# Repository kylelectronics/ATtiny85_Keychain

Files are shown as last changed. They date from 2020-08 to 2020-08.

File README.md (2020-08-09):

# Lighted Keychain
[madewith](https://img.shields.io/badge/made%20with-KiCad-blue)

ATtiny85-based illuminated PCB keychain featuring an organization symbol.
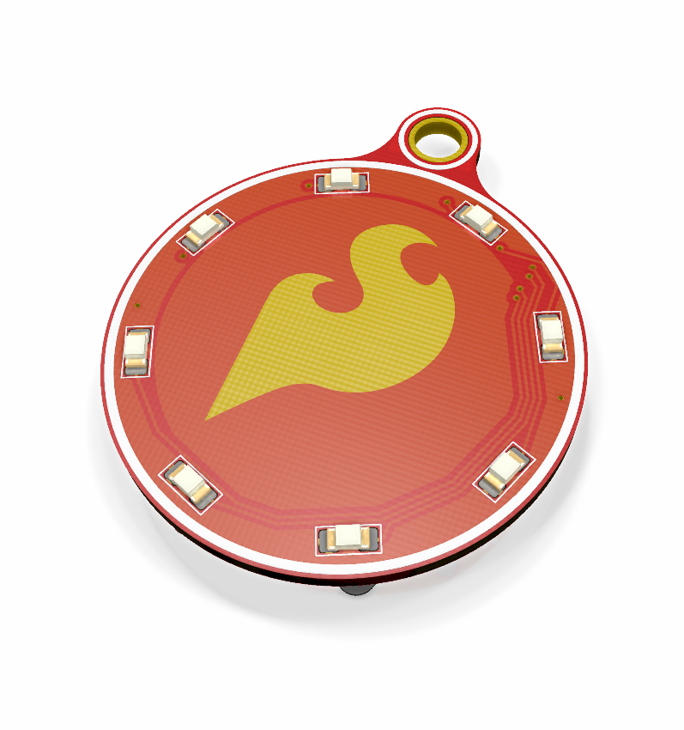
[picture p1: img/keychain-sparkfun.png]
keychain


## Description
Originally developed for Ruddock House of Caltech, this repo contains modified files featuring the flame logo of Sparkfun Electronics.

This is a 1.6" by 1.9" PCB keychain featuring an organization crest on the top copper, based on [https://github.com/ElectronicToast/ruddblink]. A ring of 8 LEDs around the crest is controlled by an ATtiny85 through a 74HC595 shift register. This keychain is intended to be compact and aesthetic, but also simple to hand solder; all packages are SOIC and 0805 or larger.

The keychain is powered by a CR2032 coin cell through the coin cell holder footprint on the back, or through an alternative power source (2.7-5.5V) soldered to those pads.

## Features
- ATtiny85 in SOIC-8 package driving 74HC595 shift register in SOIC-16 package
- PWM-able output
- Power switch
- User pushbutton
- MOSFET polarity protection
- PTC fuse
- No through hole components

## Notes

No input voltage regulation is present. Do not apply more than 5.5 V, the maximum voltage for the ATtiny.

This PCB is designed with KiCad EDA 5.1.6. Schematic and board files may be found under `/attiny85-keychain`, with documentation under `/attiny85-keychain/doc`.

## Author
- Kyle Piper - Undergraduate, Mechanical Engineering, Caltech Class of 2024
- Original design by Ray Sun, Electrical Engineering, Caltech Class of 2020

## License
<br />Unless otherwise noted, this schematic and PCB design, with associated symbol and footprint files, are licensed under a <a rel="license" href="http://creativecommons.org/licenses/by-sa/4.0/">Creative Commons Attribution-ShareAlike 4.0 International License</a>. Flame logo is property of Sparkfun Electronics.

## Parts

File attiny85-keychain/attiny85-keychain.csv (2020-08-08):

Source: | ruddblink.sch
Date: | 8/20/2019 22:31
Tool: | Eeschema (5.1.4)-1
Generator: | C:\Program Files\KiCad\bin\scripting\plugins/bom_csv_grouped_by_value_with_fp.py
Component Count: | 29
Ref | Qnty | Value | Cmp name | Footprint | Description | Vendor
BT1, | 1 | 3034 | Battery_Cell | ruddblink:BatteryHolder_Keystone_3034_Wide | Single-cell battery
C1, C2, | 2 | 0.1uF | C_Small | Capacitor_SMD:C_0805_2012Metric_Pad1.15x1.40mm_HandSolder | Unpolarized capacitor, small symbol
D1, D2, D3, D4, D8, D7, D6, D5, | 8 | 150120BS75000 | LED_Small_ALT | ruddblink:LED_1206_Uniform_HandSolder | Light emitting diode, small symbol, filled shape
F1, | 1 | 0ZCJ0005FF2E | Fuse_Small | Fuse:Fuse_1206_3216Metric_Pad1.42x1.75mm_HandSolder | Fuse, small symbol
H1, | 1 | KEYHOLE | MountingHole_Pad | ruddblink:MountingHole_Keyring | Mounting Hole with connection
Q1, | 1 | IRFML8244 | BSS138 | Package_TO_SOT_SMD:SOT-23_Handsoldering | 50V Vds, 0.22A Id, N-Channel MOSFET, SOT-23
R1, R2, R3, R4, R8, R7, R6, R5, | 8 | R | R_Small_US | Resistor_SMD:R_0805_2012Metric_Pad1.15x1.40mm_HandSolder | Resistor, small US symbol
R11, R9, R10, | 3 | 10K | R_Small_US | Resistor_SMD:R_0805_2012Metric_Pad1.15x1.40mm_HandSolder | Resistor, small US symbol
SW1, | 1 | JS202011JCQN | SW_DPDT_x2 | ruddblink:SW_SPDT_CK-JS202011JCQN | Switch, dual pole double throw, separate symbols
SW2, | 1 | PTS526 SK15 SMTR2 LFS | SW_Push | ruddblink:SW_Push_PTS526 | Push button switch, generic, two pins
U1, | 1 | ATtiny85-20SU | ATtiny85-20SU | Package_SO:SOIJ-8_5.3x5.3mm_P1.27mm | 20MHz, 8kB Flash, 512B SRAM, 512B EEPROM, debugWIRE, SOIJ-8
U2, | 1 | 74HC595 | 74HC595 | Package_SO:SOIC-16_3.9x9.9mm_P1.27mm | 8-bit serial in/out Shift Register 3-State Outputs

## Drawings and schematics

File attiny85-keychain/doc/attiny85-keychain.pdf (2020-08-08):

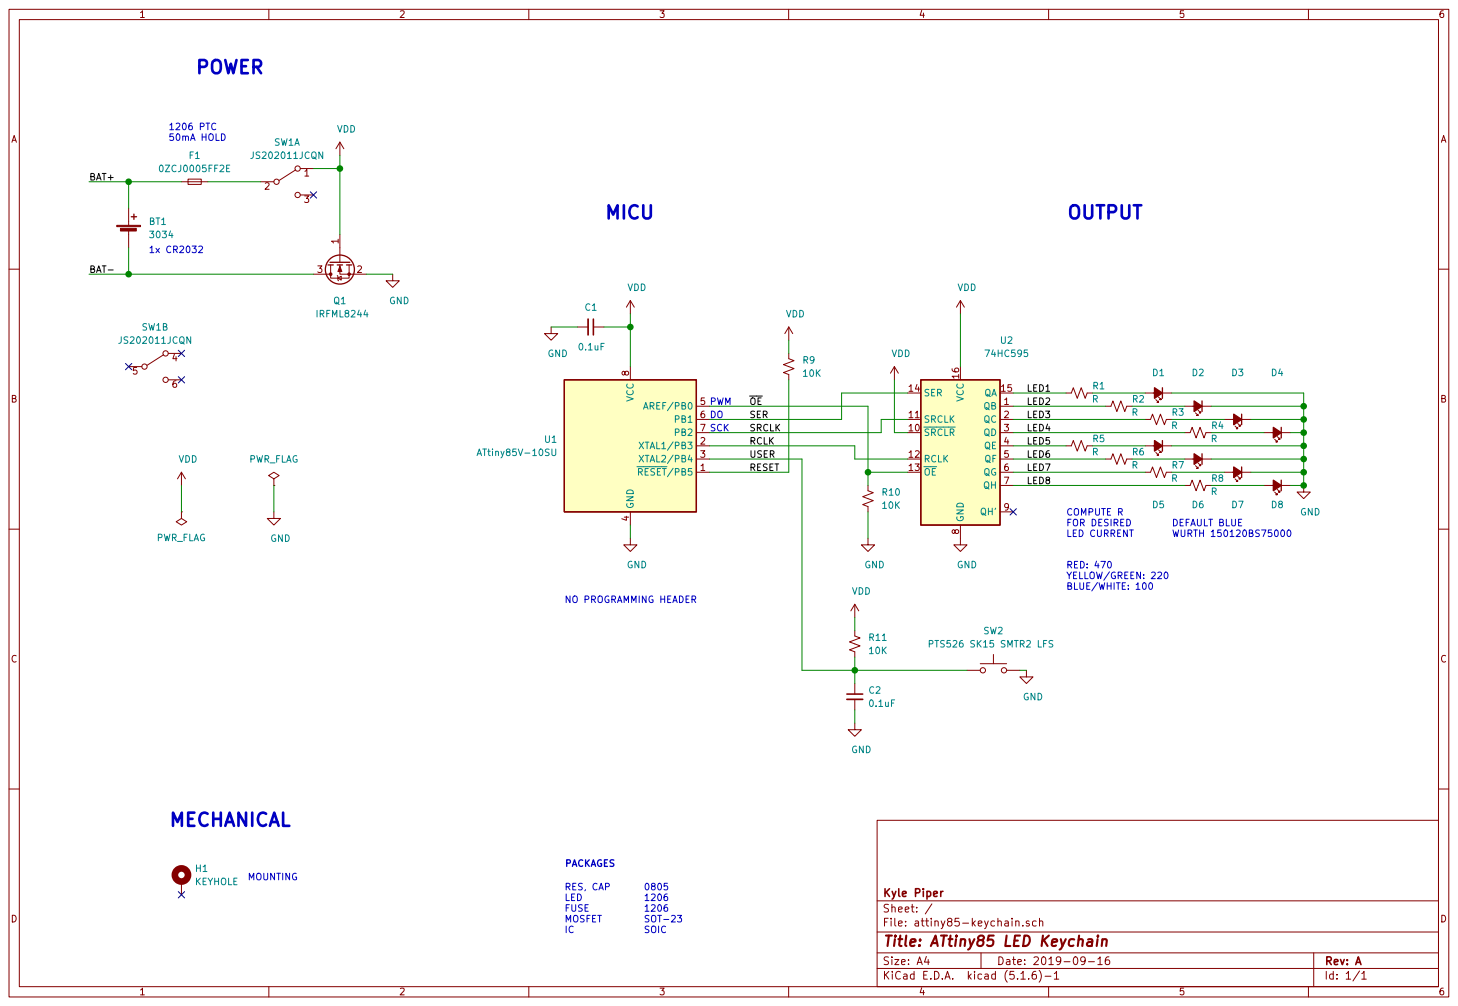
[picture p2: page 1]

PWM
RED: 470 YELLOW/GREEN: 220 BLUE/WHITE: 100 DO

Id: 1/1 Title: ATtiny85 LED Keychain

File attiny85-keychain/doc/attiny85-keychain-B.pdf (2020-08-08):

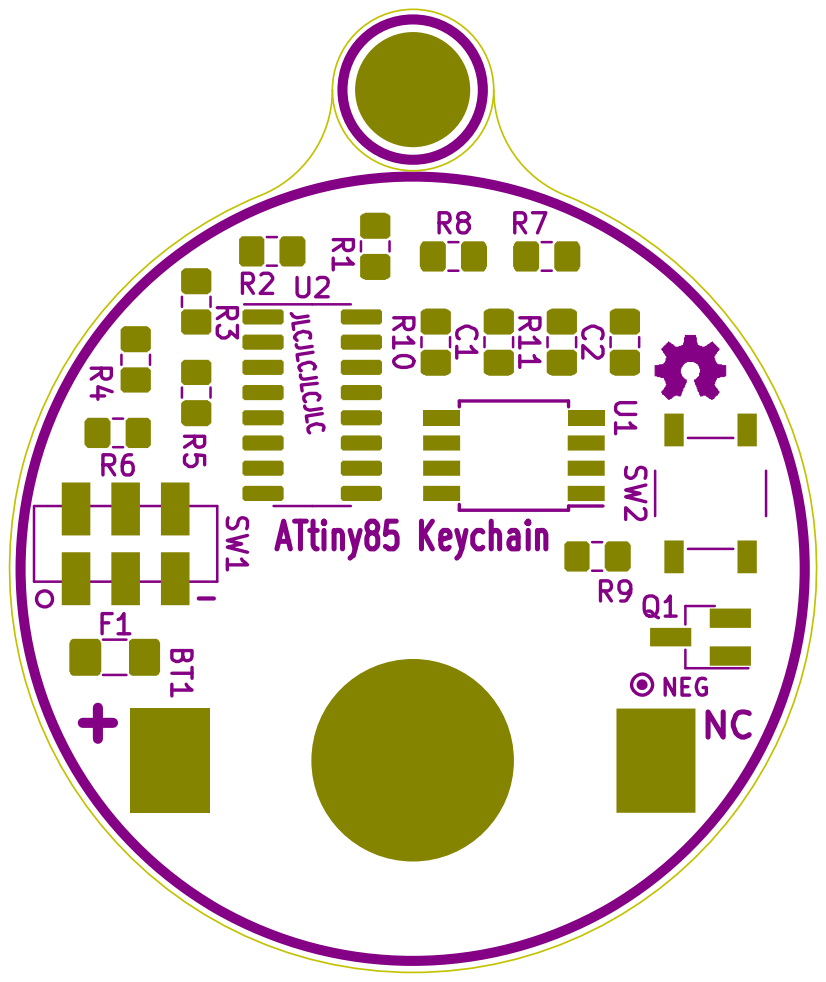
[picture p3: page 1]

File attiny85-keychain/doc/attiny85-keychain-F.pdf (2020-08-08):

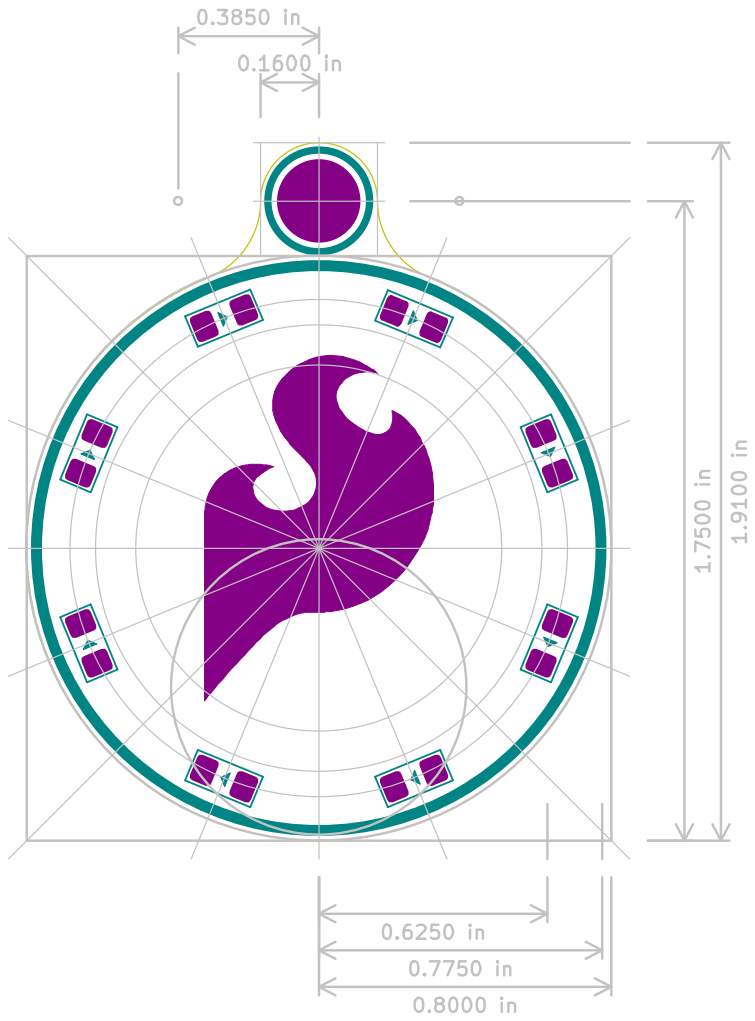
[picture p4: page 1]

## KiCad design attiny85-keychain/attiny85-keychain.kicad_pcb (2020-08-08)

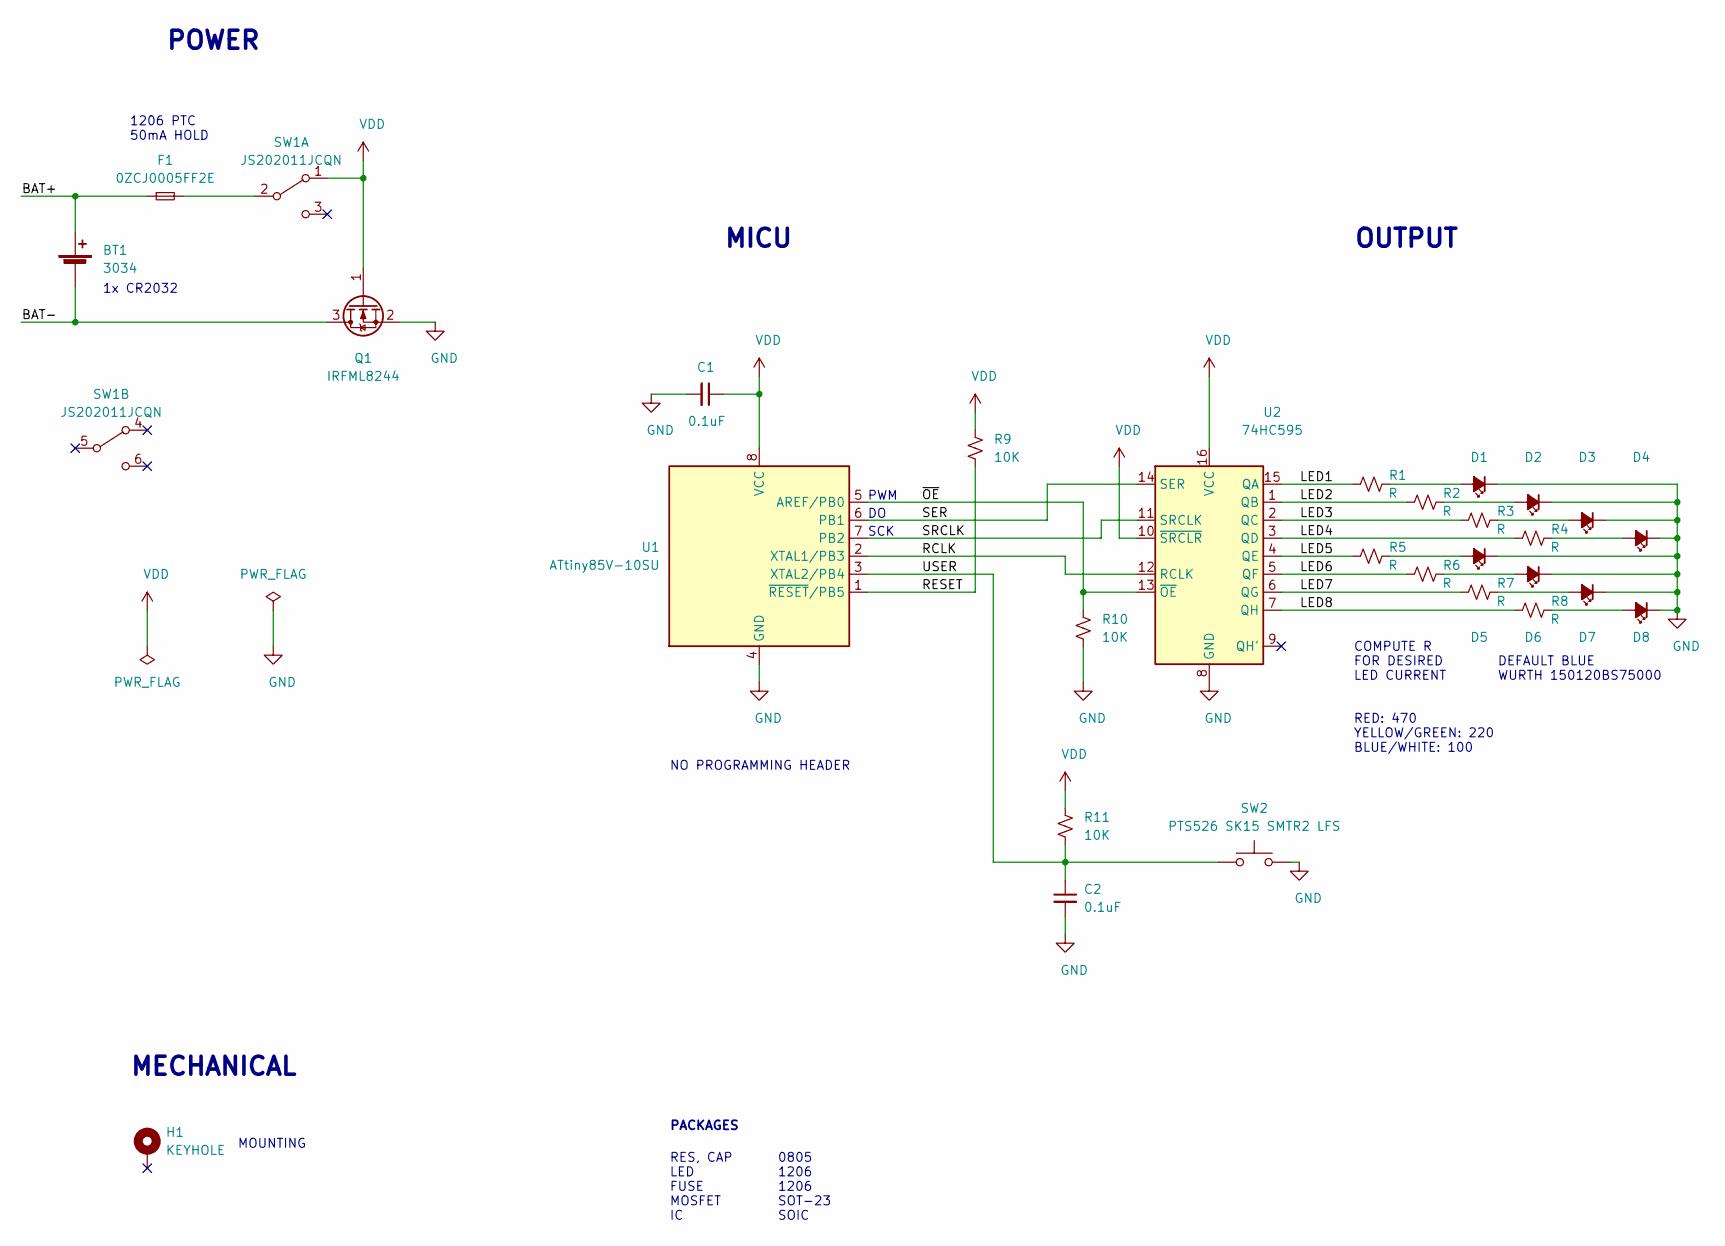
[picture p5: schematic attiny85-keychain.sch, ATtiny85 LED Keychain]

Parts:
BT1: 3034; BatteryHolder_Keystone_3034_Wide
C1, C2: 0.1uF; C_0805_2012Metric_Pad1.15x1.40mm_HandSolder
D1, D2, D3, D4, D5, D6, D7, D8: 150120BS75000; LED_1206_Uniform_HandSolder
F1: 0ZCJ0005FF2E; Fuse_1206_3216Metric_Pad1.42x1.75mm_HandSolder
H1: KEYHOLE; MountingHole_Keyring
Q1: IRFML8244; SOT-23_Handsoldering
R1, R2, R3, R4, R5, R6, R7, R8: R; R_0805_2012Metric_Pad1.15x1.40mm_HandSolder
R9, R10, R11: 10K; R_0805_2012Metric_Pad1.15x1.40mm_HandSolder
SW1: JS202011JCQN; SW_SPDT_CK-JS202011JCQN
SW2: PTS526 SK15 SMTR2 LFS; SW_Push_PTS526
U1: ATtiny85V-10SU; SOIJ-8_5.3x5.3mm_P1.27mm
U2: 74HC595; SOIC-16_3.9x9.9mm_P1.27mm

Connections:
/BAT+: BT1.1 (+), F1.1
/BAT-: BT1.2 (-), Q1.3 (D)
/LED1: R1.1, U2.15 (QA)
/LED2: R2.1, U2.1 (QB)
/LED3: R3.1, U2.2 (QC)
/LED4: R4.1, U2.3 (QD)
/LED5: R5.1, U2.4 (QE)
/LED6: R6.1, U2.5 (QF)
/LED7: R7.1, U2.6 (QG)
/LED8: R8.1, U2.7 (QH)
/RCLK: U1.2 (XTAL1/PB3), U2.12 (RCLK)
/RESET: R9.2, U1.1 (~RESET~/PB5)
/SER: U1.6 (PB1), U2.14 (SER)
/SRCLK: U1.7 (PB2), U2.11 (SRCLK)
/USER: C2.1, R11.2, SW2.1, U1.3 (XTAL2/PB4)
/~OE: R10.1, U1.5 (AREF/PB0), U2.13 (~OE)
GND: C1.2, C2.2, D1.1 (K), D2.1 (K), D3.1 (K), D4.1 (K), D5.1 (K), D6.1 (K), D7.1 (K), D8.1 (K), Q1.2 (S), R10.2, SW2.2, U1.4 (GND), U2.8 (GND)
unnamed: D1.2 (A), R1.2
unnamed: D2.2 (A), R2.2
unnamed: D3.2 (A), R3.2
unnamed: D4.2 (A), R4.2
unnamed: D5.2 (A), R5.2
unnamed: D6.2 (A), R6.2
unnamed: D7.2 (A), R7.2
unnamed: D8.2 (A), R8.2
unnamed: F1.2, SW1.2 (B)
VDD: C1.1, Q1.1 (G), R9.1, R11.1, SW1.1 (A), U1.8 (VCC), U2.10 (~SRCLR), U2.16 (VCC)

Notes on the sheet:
NO PROGRAMMING HEADER
POWER
MICU
OUTPUT
SCK
DEFAULT BLUE WURTH 150120BS75000
MOUNTING
MECHANICAL
COMPUTE R FOR DESIRED LED CURRENT
PACKAGES
RES, CAP LED FUSE MOSFET IC
0805 1206 1206 SOT-23 SOIC
1x CR2032
1206 PTC 50mA HOLD
RED: 470 YELLOW/GREEN: 220 BLUE/WHITE: 100
PWM

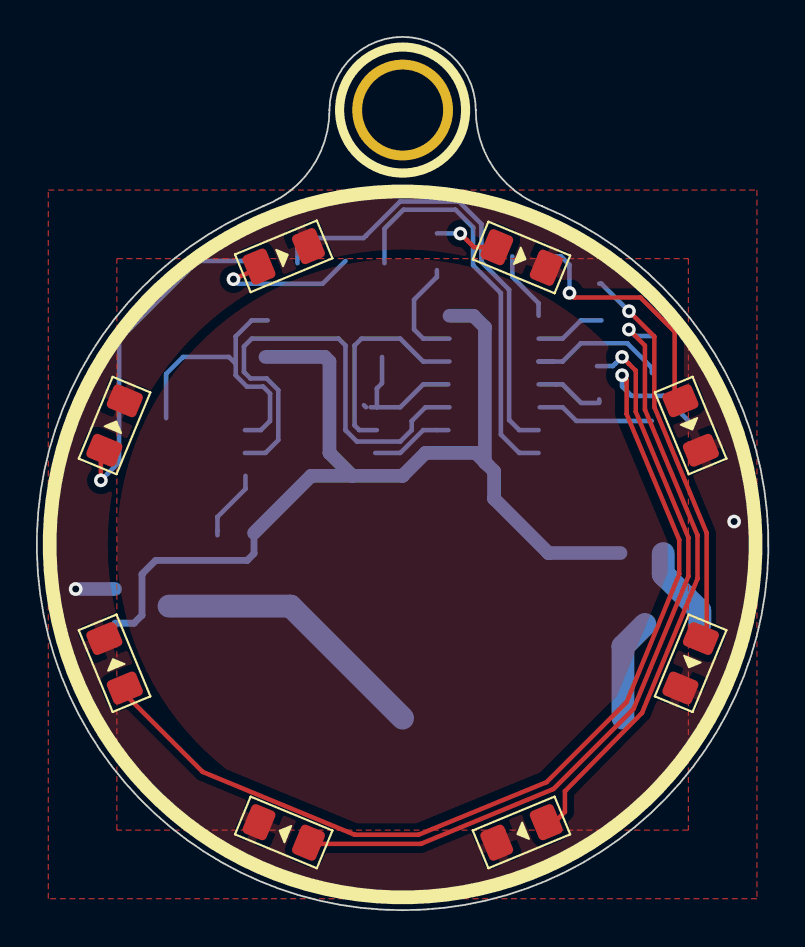
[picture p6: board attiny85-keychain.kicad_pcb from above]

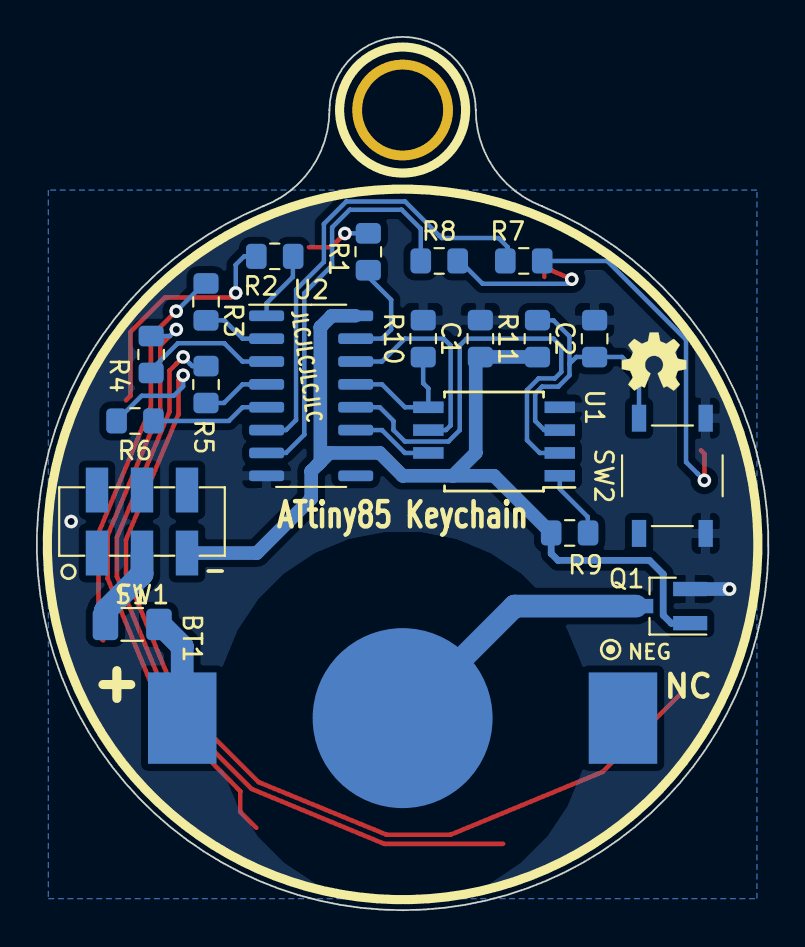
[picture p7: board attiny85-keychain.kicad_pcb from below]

Board: 2 copper layers, 40.6 x 48.5 mm, 29 parts (20 on the bottom side), 27 nets.

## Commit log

2019-07-05 Make KiCad project
    [ruddock-crest-blinky.kicad_pcb, ruddock-crest-blinky.sch]
2019-07-05 Start design
    [ruddock-crest-blinky.sch]
2019-07-07 Add old PCB library
2019-07-07 Continue design
    [ruddock-crest-blinky.kicad_pcb, ruddock-crest-blinky.sch]
2019-07-07 Move files
    [ruddock-crest-blinky.kicad_pcb, ruddock-crest-blinky.sch]
2019-07-17 Choose polarity protection MOSFET
    [ruddock-crest-blinky.kicad_pcb, ruddock-crest-blinky.sch]
2019-07-21 Select battery holder and switches
    [ruddock-crest-blinky.kicad_pcb, ruddock-crest-blinky.sch]
2019-07-21 Replace resistor packs with discrete resistors
    [ruddock-crest-blinky.kicad_pcb, ruddock-crest-blinky.sch]
2019-07-21 Select fuse
    [ruddock-crest-blinky.kicad_pcb, ruddock-crest-blinky.sch]
2019-07-22 Definitely not driving 8 blue LEDs off single CR2032
    [ruddock-crest-blinky.kicad_pcb, ruddock-crest-blinky.sch]
2019-07-22 Add symbols for mounting hole and crest copper
    [ruddock-crest-blinky.kicad_pcb, ruddock-crest-blinky.sch]
2019-07-22 Add labels to MCU pins
    [ruddock-crest-blinky.kicad_pcb, ruddock-crest-blinky.sch]
2019-07-22 Replace MOSFET with SOT-23 for easier soldering
    [ruddock-crest-blinky.kicad_pcb, ruddock-crest-blinky.sch]
2019-07-23 Design for 2 3V cells in series
    [ruddock-crest-blinky.sch]
2019-07-25 Replace LDO
    [ruddock-crest-blinky.sch]
2019-07-30 Add pulldown to ~OE
    [ruddock-crest-blinky.sch]
2019-08-05 Begin layout
    [ruddock-crest-blinky.kicad_pcb, ruddock-crest-blinky.sch]
2019-08-07 Remove dual cell and JST option, continue design
    [ruddock-crest-blinky.kicad_pcb, ruddock-crest-blinky.sch]
2019-08-08 Update power switch
    [ruddock-crest-blinky.kicad_pcb, ruddock-crest-blinky.sch]
2019-08-09 Continue placement
    [ruddock-crest-blinky.kicad_pcb, ruddock-crest-blinky.sch]
2019-08-10 Finish placement
    [ruddock-crest-blinky.kicad_pcb]
2019-08-12 Rename project
    [ruddblink.kicad_pcb, ruddblink.sch]
2019-08-12 Add mounting hole footprint
2019-08-12 Begin routing
    [ruddblink.kicad_pcb, ruddblink.sch]
2019-08-12 Rename pushbutton footprint
    [ruddblink.kicad_pcb, ruddblink.sch]
2019-08-14 Remove unnecessary crest copper pad component
    [ruddblink.sch]
2019-08-14 Did most routing
    [ruddblink.kicad_pcb]
2019-08-15 Fix footprint courtyard
2019-08-15 Pass ERC
    [ruddblink.sch]
2019-08-15 Finish routing
    [ruddblink.kicad_pcb]
2019-08-15 Position designators
    [ruddblink.kicad_pcb]
2019-08-16 Add soldermask crest with appropriate scale
2019-08-16 Remove silkscreen
2019-08-16 Update footprint path
    [ruddblink.sch]
2019-08-16 Finish board design
    [ruddblink.kicad_pcb]
2019-08-16 Fix some designator positioning
    [ruddblink.kicad_pcb]
2019-08-16 Add dimensions
    [ruddblink.kicad_pcb]
2019-08-17 Add soldermask clearance into footprint itself
2019-08-17 Create symmetric 1206 LED footprint
2019-08-17 Adjust some positions and shrink soldermask clearance
    [ruddblink.kicad_pcb, ruddblink.sch]
2019-08-17 Reposition some designators
    [ruddblink.kicad_pcb]
2019-08-17 Vanity edits
    [ruddblink.kicad_pcb]
2019-08-17 Shrink negative pad mask clearance to avoid DRC complaint
    [ruddblink.kicad_pcb]
2019-08-17 Remove target and edit dimension drawings
    [ruddblink.kicad_pcb]
2019-08-17 Add OSHW symbol
    [ruddblink.kicad_pcb]
2019-08-18 Migrate to KiCad 5.1.4 and tidy up
    [ruddblink.sch]
2019-08-18 Additional cosmetic edits
    [ruddblink.kicad_pcb]
2019-08-18 Move footprint directory
2019-08-18 Fix some DFM issues
    [ruddblink.kicad_pcb]
2019-08-19 More cosmetic edits
    [ruddblink.kicad_pcb]
2019-08-19 Move dimension marker
    [ruddblink.kicad_pcb]
2019-08-19 Fix vertical dimension mark
    [ruddblink.kicad_pcb]
2019-08-19 Make pushbutton pads slightly wider
    [ruddblink.kicad_pcb]
2019-08-20 Add top pour to keyhole neck
    [ruddblink.kicad_pcb]
2019-08-20 Clean up dimension drawings
    [ruddblink.kicad_pcb]
2019-08-20 Remove neck zone
    [ruddblink.kicad_pcb]
2019-08-21 Generate BOM
    [ruddblink.csv]
2019-08-24 Propose alternative pinout for USI shift register write control
    [ruddblink.kicad_pcb, ruddblink.sch]
2019-08-24 Update schematic
    [ruddblink.sch]
2019-08-26 Make logo smaller
    [ruddblink.sch]
2019-08-26 Move additional traces for cosmetics
    [ruddblink.kicad_pcb]
2019-08-26 Generate fabrication prints
2019-08-26 Generate gerbers for prototype production
    [ruddblink-B_Cu.gbl, ruddblink-B_Mask.gbs, ruddblink-B_SilkS.gbo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]
2019-09-17 Versioning for production version
    [ruddblink-B_Cu.gbl, ruddblink-B_Mask.gbs, ruddblink-B_SilkS.gbo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]
2019-09-17 Replace ATtiny85-20SU with ATtiny85V-10SU for more usable battery capacity
    [ruddblink.kicad_pcb, ruddblink.sch]
2019-09-17 Change reference C3 to C2
    [ruddblink.kicad_pcb, ruddblink.sch]
2019-10-31 Generate Gerbers for production
    [ruddblink-B_Cu.gbl, ruddblink-B_Mask.gbs, ruddblink-B_SilkS.gbo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]
2019-10-31 Update BOM
    [ruddblink.csv]
2019-12-06 Fix front fab print
